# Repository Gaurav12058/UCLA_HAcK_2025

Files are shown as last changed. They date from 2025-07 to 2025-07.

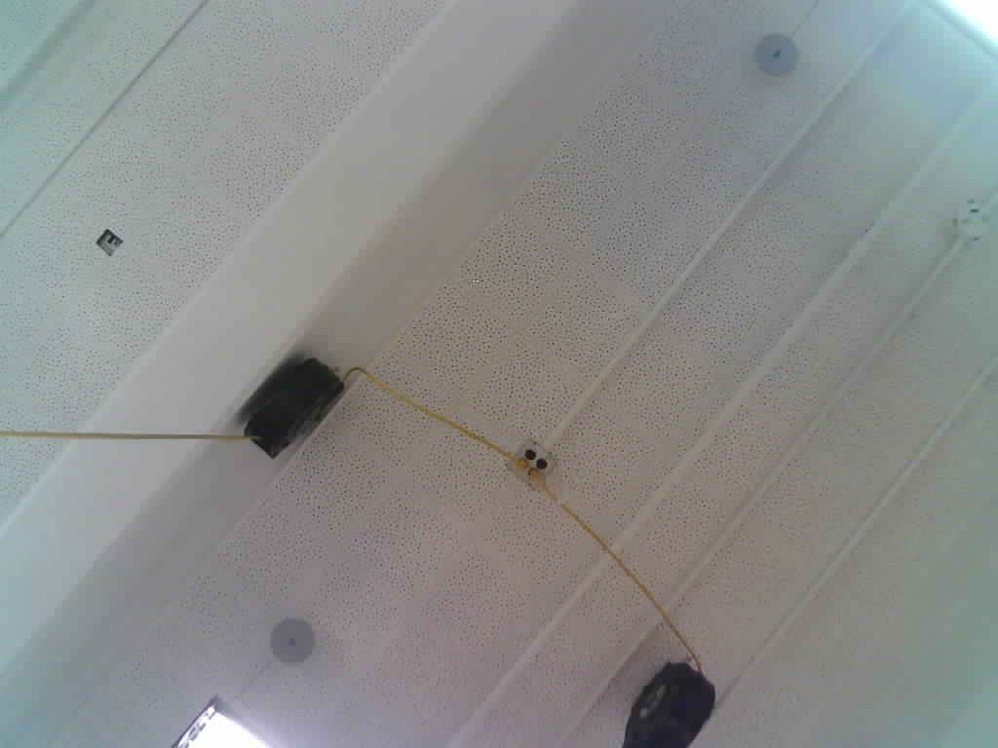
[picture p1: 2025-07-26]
Cam_Setup/downloaded_image.jpg

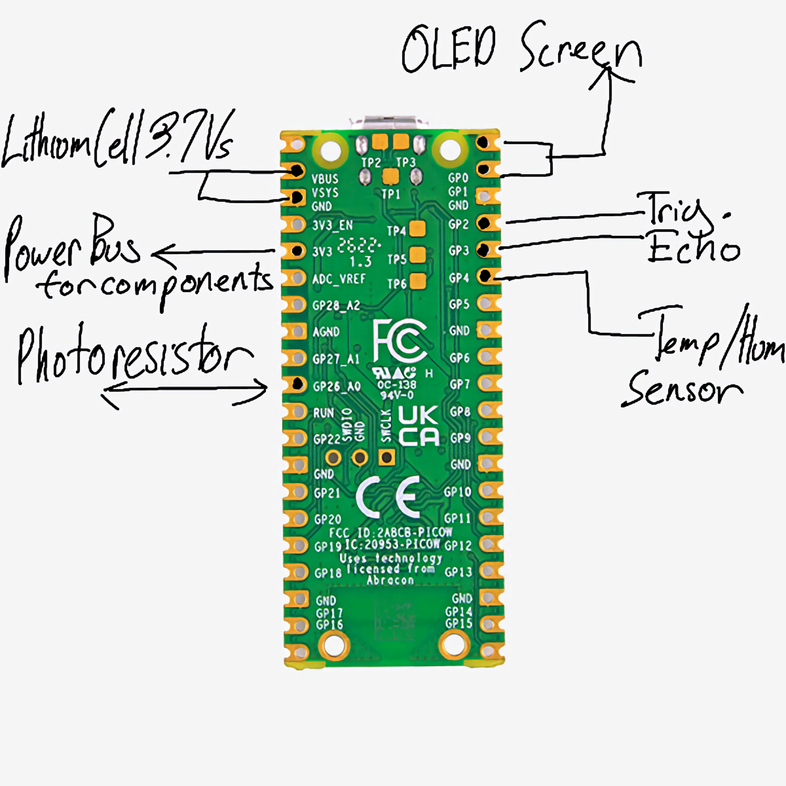
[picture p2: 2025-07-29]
Circuit Schematics/picodiagram.png

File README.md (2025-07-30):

# UCLA HAcK 2025
This REPO contains all the files/code we created during the UCLA HAcK 2025 Challenge

Design Review Presentation: https://drive.google.com/uc?id=1Txfxj7n8K6vMZTReTSZA9UNYm09hm_GZ&export=download

Slides: https://docs.google.com/presentation/d/1NuzraGqRk-Ez6vw4p3RWDepRvH6QMfju0EuOWGAVrpU/edit?usp=sharing

# HAcK 2025 Theme
Wes is a famous jewelry collector.  His most prized possession, a 500 carat diamond, was stolen just last week by a thief that no one could track down…until now. We’ve confirmed the location of the diamond, and we’ll be sending our HAcKers in to retrieve it.  However, we are expecting heavy security, so it won’t be easy finding the jewel. Insider information gave us insight on the security measures they have in place, and you must construct a device that will aid you in deciphering them.

HAcKers will send in one agent equipped with a wearable spy device of their own creation to infiltrate the Secure Base where the diamond is being held. The agent will communicate and send data to their operator (in another room) who will guide the agent by sending messages back to interpret clues, decode information and recover the diamond.

# Technical Challenge
You will need to construct a device (or series of devices) that meets the following requirements:
- Your device(s) must attach to the operator without them having to hold or support them with their hands.
- Your device(s) must resemble wearable accessories/articles of clothing, and should be disguised or otherwise discreet.
- Your device(s) must contain/conceal electrical components
- A device must feature your team logo on it

Our intel suggests that your prototype will need to be able to perform the following tasks:
- Your pico must be able to gather accurate temperature and humidity data to analyze the active field environment
- Your pico must be able to measure light levels and determine distances between objects
- Your ESP-32 cam must be able to take photos that save to the operator’s laptop
- All collected data must be sent to the operator at the bay station for further decoding/analysis

You must also create a website for your operator at the bay station to use:
- Your website must operate the camera, deciding when to  take a picture
- All data received from the agent must be visible on  the website (Temperature in F, Distance in cm, Humidity %, Light in lumens)
- Your website must be able to make api calls to our supercomputer back at HQ (ChatGPT) in order to audibly decipher any additional unknowns
- The results of your api calls must also be viewable on the website
- Your website must be able to communicate information from the operator to the agent in the field

Should anything happen to you or your fellow agents, our team must be able to reproduce your prototypes. As such, you will be required to document the following:
- All code must be uploaded to a GitHub repository and be properly updated.
- You must create and save a CAD for each part of your design.
- You must maintain a simple schematic of your circuits that contains the wiring route and the electrical components used.

# Backend and Frontend setup

- In the backend directory, create a file named '.env', and add the following:

- CONNECT_URL=mqtts://(your URL):(your port)

- MQTT_USER=(your user)

- MQTT_PASS=(your pass)

- Then, while in the backend directory, install the dependencies by running
### `npm install`
- You can start the backend by running 
### `node index.js`

- In a separate terminal, in the frontend directory, install the dependencies by running
### `npm install`
- You can start the frontend by running 
### `npm start`

# Using connections.py for your Pico 2W

- You will be able to use 2 functions in connections.py
    - One for connection to the MQTT broker (connect_mqtt) and one for connecting to WIFI (connect_internet)

    - connect_mqtt(mqtt_server, mqtt_user, mqtt_pass):

        - mqtt_server: the server url which you have obtained by making a free serverless MQTT Broker on HIVEMQ
            - Should look something like: '37##616##db7#bd1##cac997eb01##13.s1.eu.hivemq.cloud'

        - mqtt_user:
            - This is the name of the user you create when you make a credential
                - The purpose of this is just to have a unique user in which the MQTT Broker can understand where the message is coming from 
                - Ex: username = 'pico' when creating credentials for the Raspberry Pi Pico W to send something

        - mqtt_pass:
            - This is the password that goes along with your mqtt_user
            - Just for the broker to validate the user
            - Make this whatever you want, just write it down

        - RETURNS client, which you can use 
            - client.subscribe(b"topic") to subscribe to a topic of your choice
            - client.publish(b"topic", b"message") to publish a message with a topic of your choice
            - client

    - connect_internet( ssid, password ):
        
        - ssid: 
            - This is the name of the wi-fi network you are trying to connect to

        - password:
            - this is the password of the wi-fi network you are trying to connect to

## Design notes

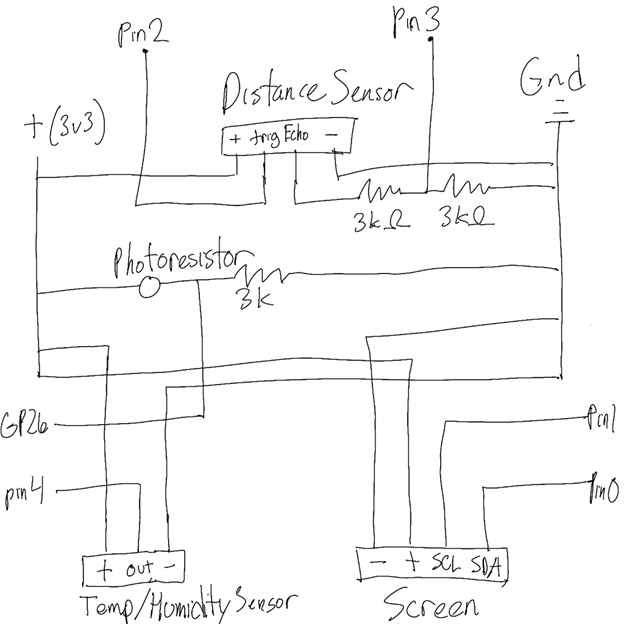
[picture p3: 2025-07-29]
Circuit Schematics/sensordiagram.png

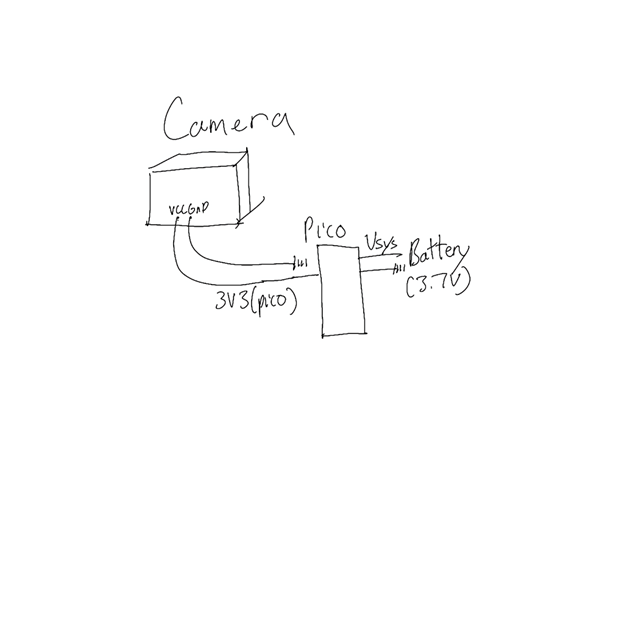
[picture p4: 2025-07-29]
Circuit Schematics/camerapowerdiagram.png

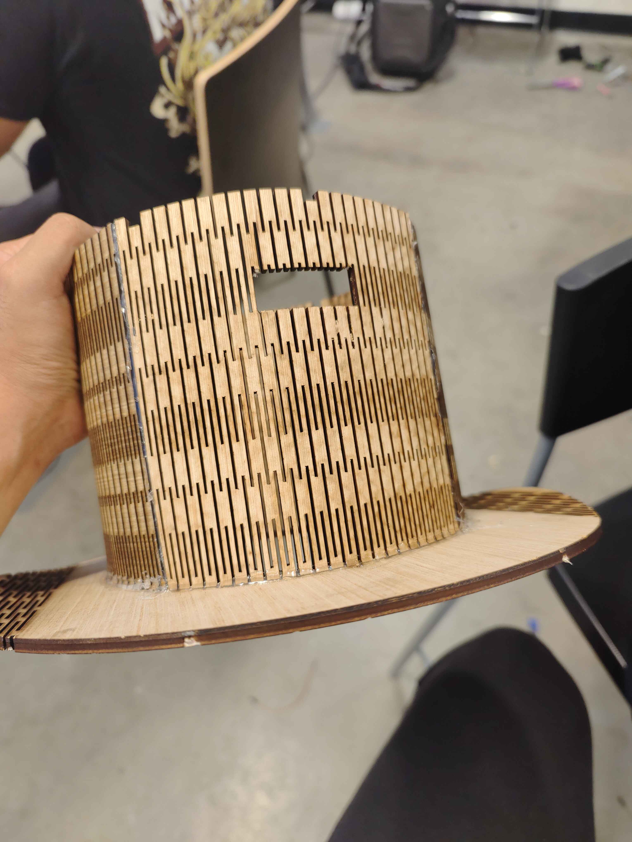
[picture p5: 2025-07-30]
Photos/hat_with_circuit_0.jpg

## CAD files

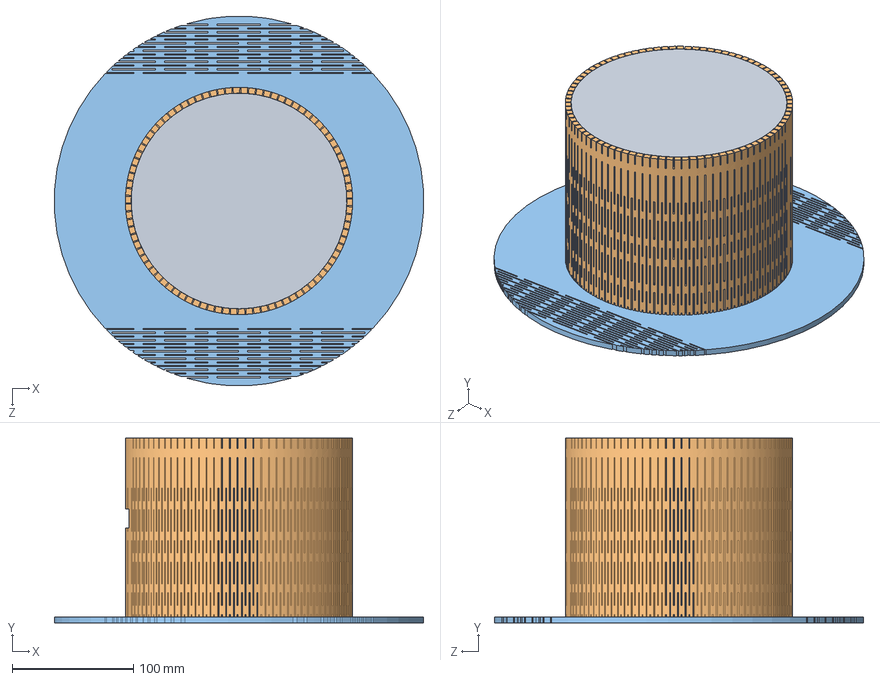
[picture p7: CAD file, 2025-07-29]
CAD/TopHat/HatAssem.SLDASM
304.3 x 152.4 x 304.3 mm
base
Cut-Extrude1
plane x 2

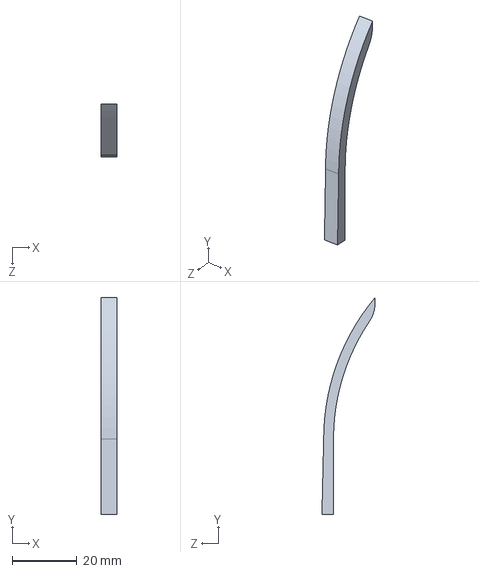
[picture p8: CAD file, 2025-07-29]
CAD/TopHat/Fillet2.SLDPRT
4.78 x 66.8 x 16.4 mm

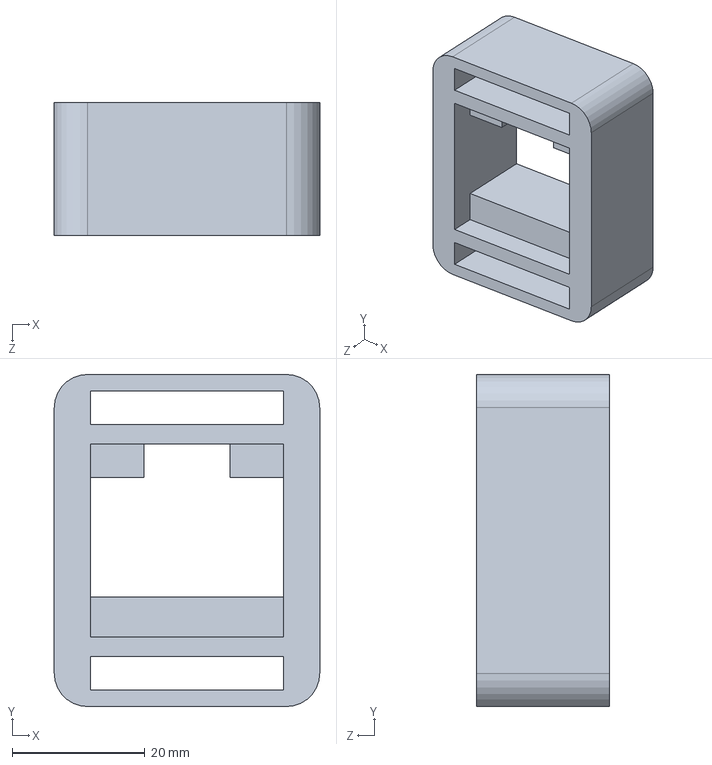
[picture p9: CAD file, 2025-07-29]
CAD/Watch.SLDPRT
40.0 x 50.0 x 20.0 mm

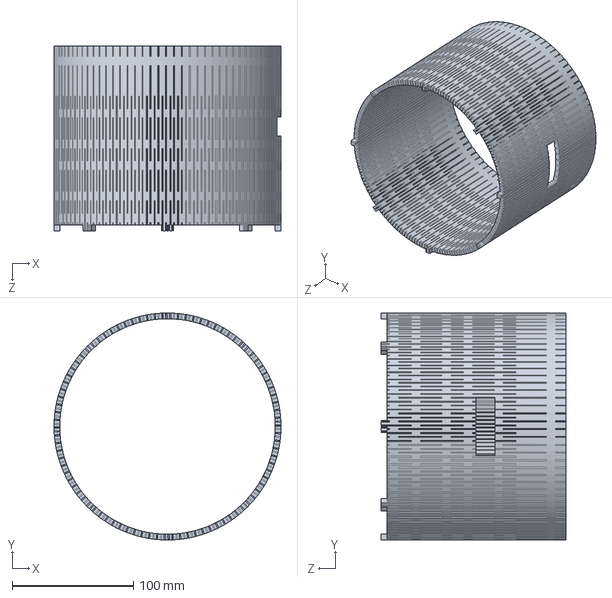
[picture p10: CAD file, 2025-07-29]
CAD/TopHat/Cut-Extrude1.SLDPRT
187.4 x 187.4 x 152.4 mm

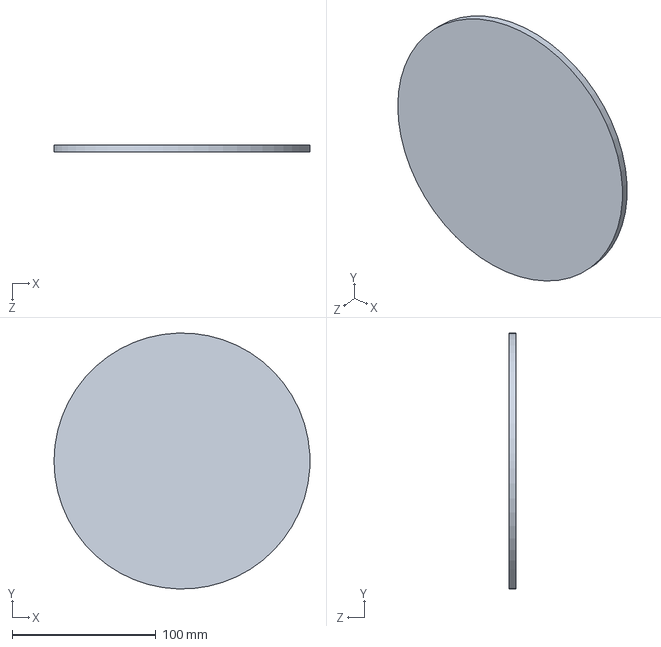
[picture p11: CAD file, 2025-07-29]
CAD/TopHat/plane.SLDPRT
177.8 x 177.7 x 4.78 mm

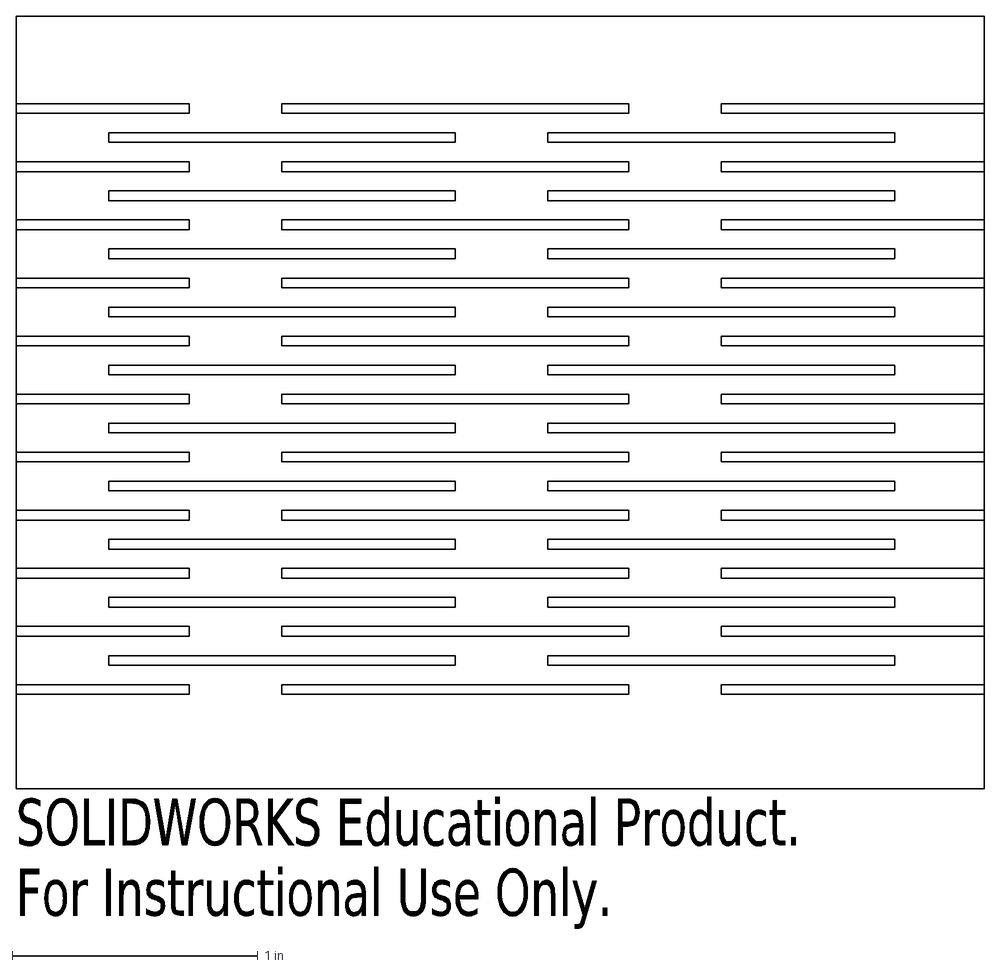
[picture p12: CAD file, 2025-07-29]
CAD/HatLivingHinge.DXF
SOLIDWORKS Educational Product.
For Instructional Use Only.

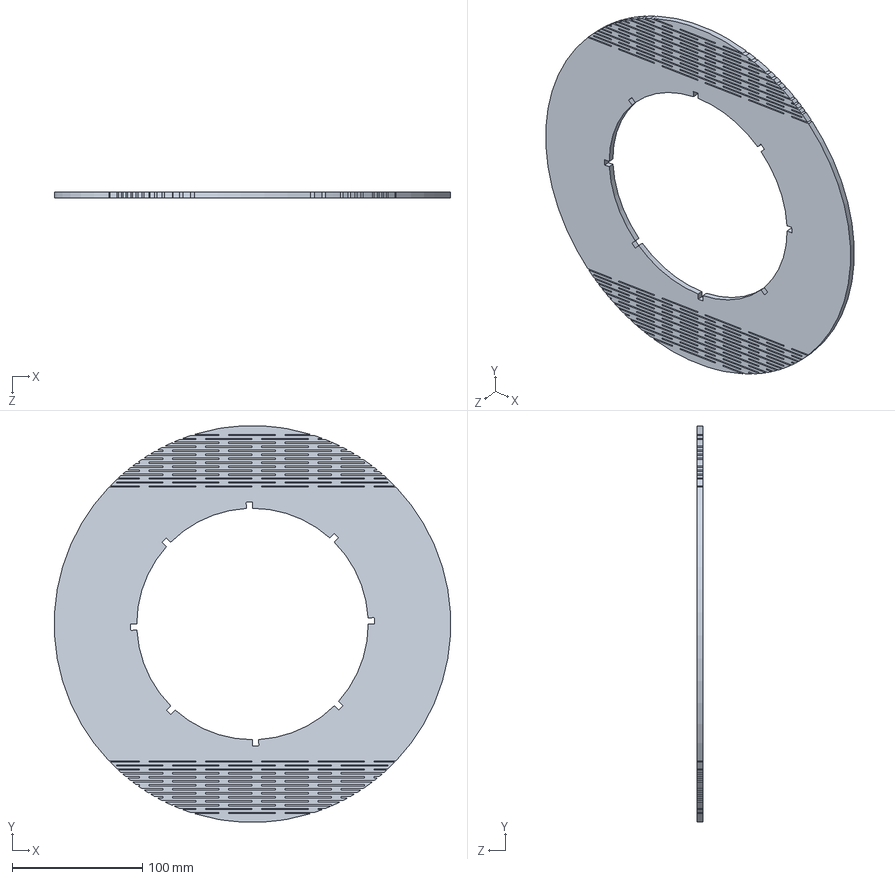
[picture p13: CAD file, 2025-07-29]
CAD/TopHat/base.SLDPRT
304.3 x 304.3 x 4.78 mm

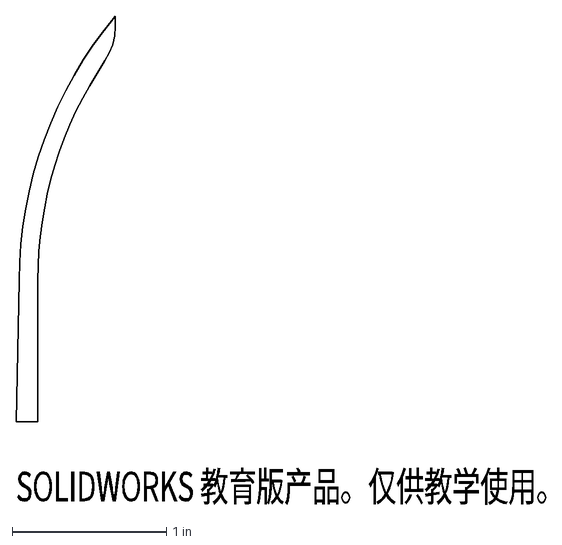
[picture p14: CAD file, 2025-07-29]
CAD/TopHat/Hatframe.DXF
SOLIDWORKS 教育版产品。仅供教学使用。

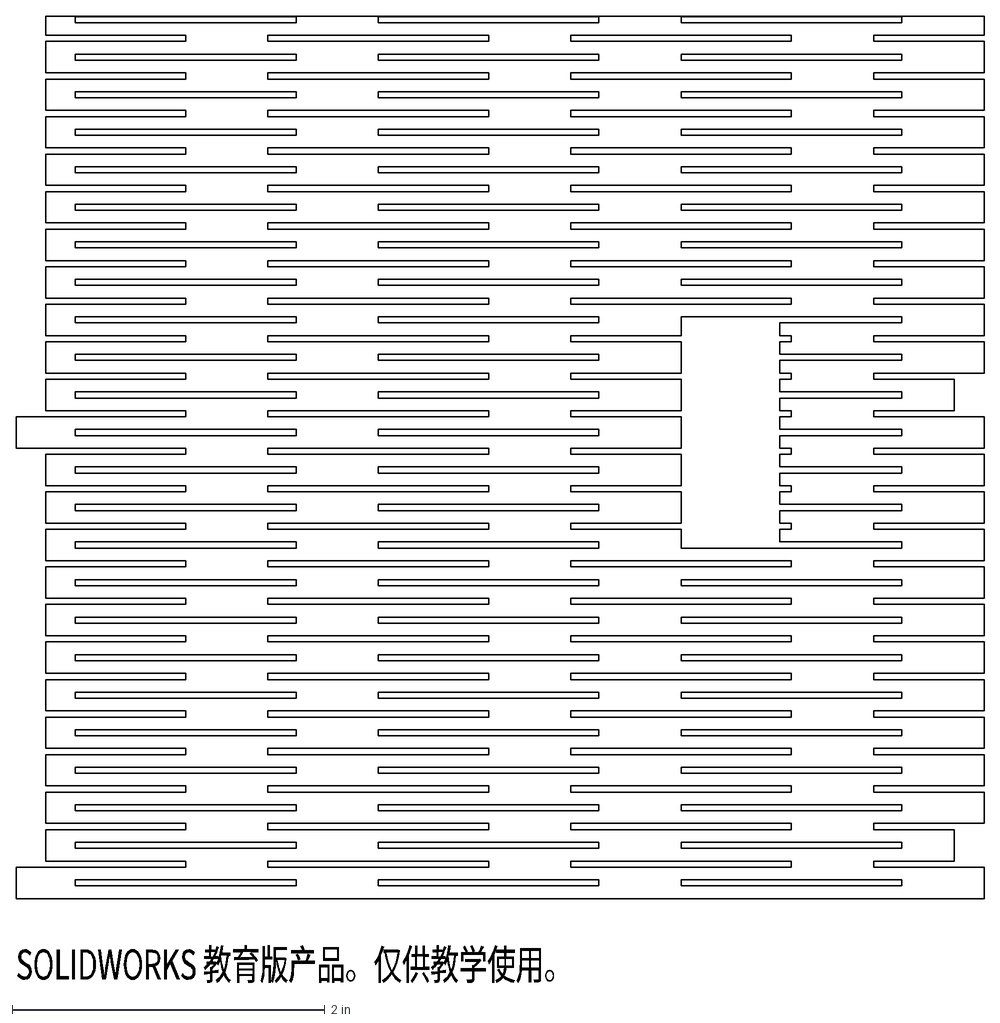
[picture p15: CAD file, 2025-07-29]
CAD/TopHat/Hatboard cut.DXF
SOLIDWORKS 教育版产品。仅供教学使用。

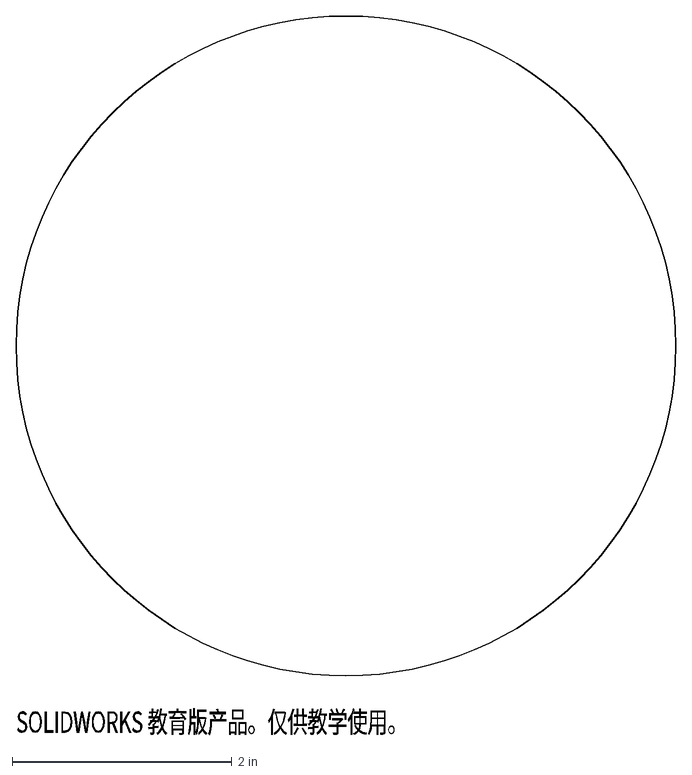
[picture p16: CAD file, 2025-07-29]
CAD/TopHat/HatTopBase.DXF
SOLIDWORKS 教育版产品。仅供教学使用。

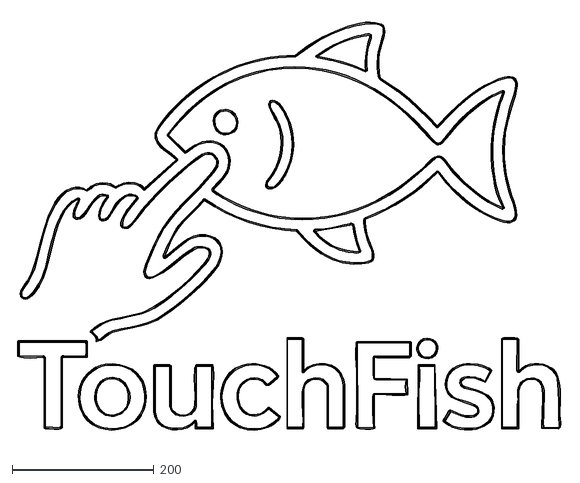
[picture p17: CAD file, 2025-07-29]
CAD/TopHat/TouchFishlogo1.dxf
774.0 x 603.0

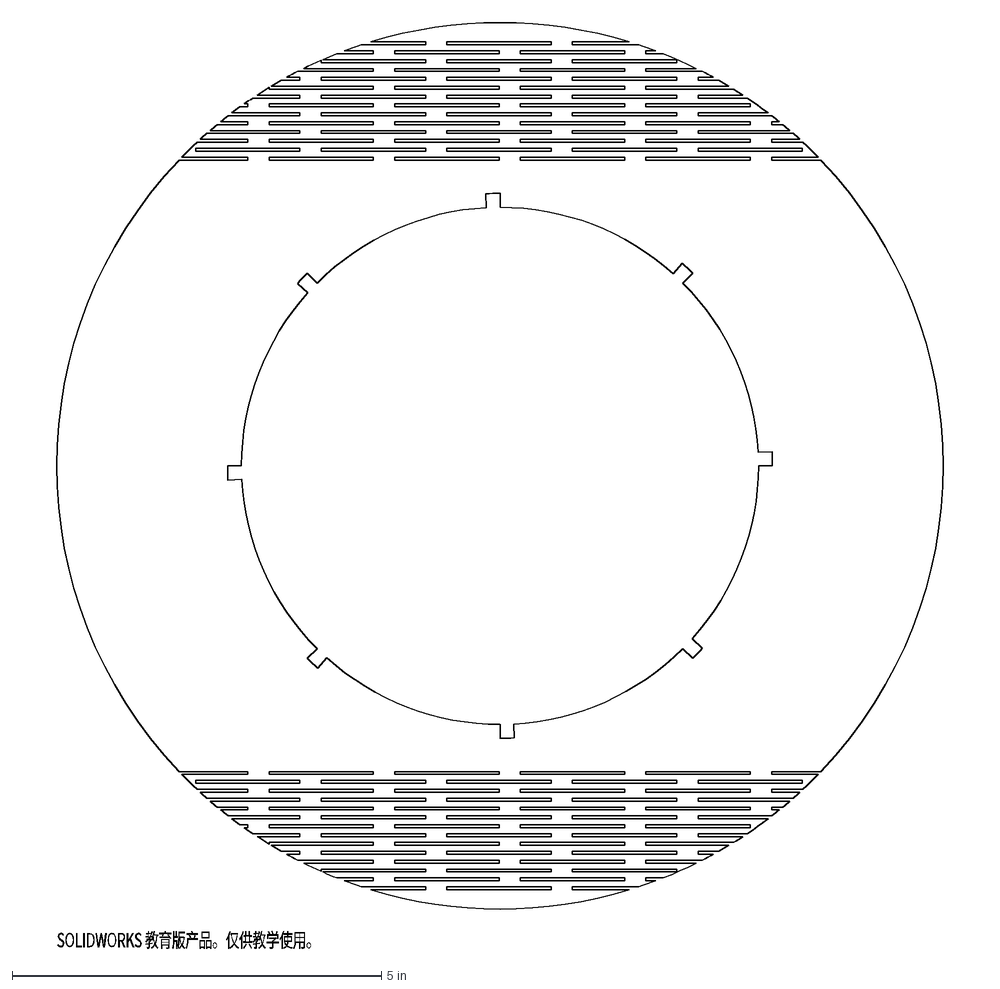
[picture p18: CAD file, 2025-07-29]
CAD/TopHat/HatBase.DXF
SOLIDWORKS 教育版产品。仅供教学使用。

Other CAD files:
CAD/TopHat/Fillet3.SLDPRT
CAD/Watch band.SLDPRT
CAD/Watch Acrylic.SLDPRT
CAD/Team15Watch.STL
CAD/HatTest.SLDPRT
CAD/HatBands.SLDPRT
CAD/HatBands.DXF
CAD/HatTest.DXF
CAD/TopHat/HatCircle.DXF
CAD/Watch Acrylic.DXF
CAD/Watch band.DXF
CAD/Watch.DXF
CAD/Watch.STL

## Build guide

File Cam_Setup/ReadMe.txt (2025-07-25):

ESP32-Camera

Uploading Code to the Camera
-Download Arduino or other C IDE
-Inside of WifiCam change WIFI_SSiD and WIFI_PASS accordingly
-Attach the camera to the daughterboard (says ..-MB on it)
-Connect to computer using USB cable
-Hold the IO0 Button and press the reset button on the Camera to enter programming mode
-Click on 'Tools'->'Manage Libraries', then donwnload the esp32cam library
-Upload the code using the upload button on the IDE
-Click reset and open the serial monitor in Arduino IDE
-Be on a baud rate of 115200 
-Check it connected to wifi successfully 
-Note the IP address -> in the form http:/....

Running the Python Code receive.py
-Make sure the IP Address in receive.py is the same as the one seen in the serial monitor

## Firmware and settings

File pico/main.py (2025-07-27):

from connections import connect_mqtt, connect_internet
from time import sleep
from machine import Pin, I2C, ADC
import time
import dht
from DIYables_MicroPython_OLED import OLED_SSD1306_I2C

# I2C OLED SETUP
i2c = I2C(0, scl=Pin(1), sda=Pin(0), freq=400000)
oled = OLED_SSD1306_I2C(128, 64, i2c)
oled.set_text_size(1)

# Ultrasonic Sensor SETUP
TRIG = Pin(2, Pin.OUT)
ECHO = Pin(3, Pin.IN)

# DHT11 Sensor SETUP
dht_pin = Pin(4, Pin.IN, Pin.PULL_UP)
dht_sensor = dht.DHT11(dht_pin)

# LDR Sensor (Photoresistor) SETUP
ldr = ADC(Pin(26))

# GLOBAL VARIABLE
incoming_oled_text = None  # Stores OLED message from MQTT

# FUNCTIONS
def read_light():
    raw = ldr.read_u16()
    lumenReading = (raw - 95) / 64751 # Our linear equation to convert adc to lumens.
    return lumenReading

def get_distance():
    TRIG.value(0)
    time.sleep_us(2)
    TRIG.value(1)
    time.sleep_us(10)
    TRIG.value(0)

    timeout = 30000
    start = time.ticks_us()
    while ECHO.value() == 0:
        if time.ticks_diff(time.ticks_us(), start) > timeout:
            return None
    pulse_start = time.ticks_us()

    start = time.ticks_us()
    while ECHO.value() == 1:
        if time.ticks_diff(time.ticks_us(), start) > timeout:
            return None
    pulse_end = time.ticks_us()

    duration = time.ticks_diff(pulse_end, pulse_start)
    distance = (duration * 0.0343) / 2
    return round(distance, 1)

def update_oled(distance, temp, hum, light):
    oled.clear_display()
    oled.set_cursor(0, 0)
    oled.println("Distance: {:.2f} cm".format(distance) if distance is not None else "Distance: Error")
    oled.set_cursor(0, 15)
    oled.println("Temp: {:.2f} °F".format(temp) if temp is not None else "Temp: Error")
    oled.set_cursor(0, 30)
    oled.println("Humidity: {:.2f} %".format(hum) if hum is not None else "Humidity: Error")
    oled.set_cursor(0, 45)
    oled.println("Light: {:.4f} lm".format(light) if light is not None else "Light: Error")
    oled.display()

def display_message(msg):
    oled.clear_display()
    oled.set_cursor(0, 0)
    oled.println("Message from Operator:")
    oled.set_cursor(0, 15)
    oled.println(msg[:20])  # 1st line (max 20 chars)
    oled.set_cursor(0, 30)
    oled.println(msg[20:40])  # 2nd line (next 20 chars)
    oled.set_cursor(0, 45)
    oled.println(msg[40:60])  # 3rd line (next 20 chars)
    oled.display()

# CALLBACK FOR MQTT
def on_message(topic, msg):
    global incoming_oled_text
    if topic == b"pico/oled":
        incoming_oled_text = msg.decode()

# MAIN FUNCTION
def main():
    global incoming_oled_text

    print("Connecting to WiFi...")
    connect_internet("HAcK-Project-WiFi-2", password="UCLA.HAcK.2024.Summer")

    client = connect_mqtt(
        "cd2116d580294ecb806ddd465da330cd.s1.eu.hivemq.cloud",
        "Nathan",
        "Ab123456"
    )

    client.set_callback(on_message)
    client.subscribe("pico/oled")

    print("Starting sensors...")
    time.sleep(2)

    while True:
        client.check_msg()  # Check for incoming MQTT messages

        # Display incoming OLED message if any
        if incoming_oled_text:
            print("OLED Message Received:", incoming_oled_text)
            display_message(incoming_oled_text)
            sleep(12)  # Display message for 12 seconds
            incoming_oled_text = None  # Clear after displaying

        try:
            dht_sensor.measure()
            temperature = (dht_sensor.temperature() * 9 / 5) + 32
            humidity = dht_sensor.humidity()
        except Exception as e:
            print("DHT11 Error:", e)
            temperature = None
            humidity = None

        distance = get_distance()
        light_level = read_light()

        update_oled(distance, temperature, humidity, light_level)

        # Publish sensor data to MQTT topics
        client.publish("pico/temperature", str(temperature))
        client.publish("pico/humidity", str(humidity))
        client.publish("pico/distance", str(distance))
        client.publish("pico/lightlevel", str(light_level))

        sleep(2)

# RUN FILE
if __name__ == "__main__":
    try:
        main()
    except KeyboardInterrupt:
        print("Stopped by user")

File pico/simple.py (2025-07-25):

import usocket as socket
import ustruct as struct

from ubinascii import hexlify


class MQTTException(Exception):
    pass


class MQTTClient:
    def __init__(
        self,
        client_id,
        server,
        port=0,
        user=None,
        password=None,
        keepalive=0,
        ssl=None,
    ):
        if port == 0:
            port = 8883 if ssl else 1883
        self.client_id = b"pico"  # You can customize this if needed
        self.sock = None
        self.server = "cd2116d580294ecb806ddd465da330cd.s1.eu.hivemq.cloud"
        self.port = 8883
        self.ssl = True
        self.pid = 0
        self.cb = None
        self.user = "Nathan"
        self.pswd = "Ab123456"
        self.keepalive = keepalive
        self.lw_topic = None
        self.lw_msg = None
        self.lw_qos = 0
        self.lw_retain = False

    def _send_str(self, s):
        self.sock.write(struct.pack("!H", len(s)))
        self.sock.write(s)

    def _recv_len(self):
        n = 0
        sh = 0
        while 1:
            b = self.sock.read(1)[0]
            n |= (b & 0x7F) << sh
            if not b & 0x80:
                return n
            sh += 7

    def set_callback(self, f):
        self.cb = f

    def set_last_will(self, topic, msg, retain=False, qos=0):
        assert 0 <= qos <= 2
        assert topic
        self.lw_topic = topic
        self.lw_msg = msg
        self.lw_qos = qos
        self.lw_retain = retain

    def connect(self, clean_session=True):
        self.sock = socket.socket()
        addr = socket.getaddrinfo(self.server, self.port)[0][-1]
        self.sock.connect(addr)
        if self.ssl:
            self.sock = self.ssl.wrap_socket(self.sock, server_hostname=self.server)
        premsg = bytearray(b"\x10\0\0\0\0\0")
        msg = bytearray(b"\x04MQTT\x04\x02\0\0")

        sz = 10 + 2 + len(self.client_id)
        msg[6] = clean_session << 1
        if self.user:
            sz += 2 + len(self.user) + 2 + len(self.pswd)
            msg[6] |= 0xC0
        if self.keepalive:
            assert self.keepalive < 65536
            msg[7] |= self.keepalive >> 8
            msg[8] |= self.keepalive & 0x00FF
        if self.lw_topic:
            sz += 2 + len(self.lw_topic) + 2 + len(self.lw_msg)
            msg[6] |= 0x4 | (self.lw_qos & 0x1) << 3 | (self.lw_qos & 0x2) << 3
            msg[6] |= self.lw_retain << 5

        i = 1
        while sz > 0x7F:
            premsg[i] = (sz & 0x7F) | 0x80
            sz >>= 7
            i += 1
        premsg[i] = sz

        self.sock.write(premsg, i + 2)
        self.sock.write(msg)
        # print(hex(len(msg)), hexlify(msg, ":"))
        self._send_str(self.client_id)
        if self.lw_topic:
            self._send_str(self.lw_topic)
            self._send_str(self.lw_msg)
        if self.user:
            self._send_str(self.user)
            self._send_str(self.pswd)
        resp = self.sock.read(4)
        assert resp[0] == 0x20 and resp[1] == 0x02
        if resp[3] != 0:
            raise MQTTException(resp[3])
        return resp[2] & 1

    def disconnect(self):
        self.sock.write(b"\xe0\0")
        self.sock.close()

    def ping(self):
        self.sock.write(b"\xc0\0")

    def publish(self, topic, msg, retain=False, qos=0):
        pkt = bytearray(b"\x30\0\0\0")
        pkt[0] |= qos << 1 | retain
        sz = 2 + len(topic) + len(msg)
        if qos > 0:
            sz += 2
        assert sz < 2097152
        i = 1
        while sz > 0x7F:
            pkt[i] = (sz & 0x7F) | 0x80
            sz >>= 7
            i += 1
        pkt[i] = sz
        # print(hex(len(pkt)), hexlify(pkt, ":"))
        self.sock.write(pkt, i + 1)
        self._send_str(topic)
        if qos > 0:
            self.pid += 1
            pid = self.pid
            struct.pack_into("!H", pkt, 0, pid)
            self.sock.write(pkt, 2)
        self.sock.write(msg)
        if qos == 1:
            while 1:
                op = self.wait_msg()
                if op == 0x40:
                    sz = self.sock.read(1)
                    assert sz == b"\x02"
                    rcv_pid = self.sock.read(2)
                    rcv_pid = rcv_pid[0] << 8 | rcv_pid[1]
                    if pid == rcv_pid:
                        return
        elif qos == 2:
            assert 0

    def subscribe(self, topic, qos=0):
        assert self.cb is not None, "Subscribe callback is not set"
        pkt = bytearray(b"\x82\0\0\0")
        self.pid += 1
        struct.pack_into("!BH", pkt, 1, 2 + 2 + len(topic) + 1, self.pid)
        # print(hex(len(pkt)), hexlify(pkt, ":"))
        self.sock.write(pkt)
        self._send_str(topic)
        self.sock.write(qos.to_bytes(1, "little"))
        while 1:
            op = self.wait_msg()
            if op == 0x90:
                resp = self.sock.read(4)
                # print(resp)
                assert resp[1] == pkt[2] and resp[2] == pkt[3]
                if resp[3] == 0x80:
                    raise MQTTException(resp[3])
                return

    # Wait for a single incoming MQTT message and process it.
    # Subscribed messages are delivered to a callback previously
    # set by .set_callback() method. Other (internal) MQTT
    # messages processed internally.
    def wait_msg(self):
        res = self.sock.read(1)
        self.sock.setblocking(True)
        if res is None:
            return None
        if res == b"":
            raise OSError(-1)
        if res == b"\xd0":  # PINGRESP
            sz = self.sock.read(1)[0]
            assert sz == 0
            return None
        op = res[0]
        if op & 0xF0 != 0x30:
            return op
        sz = self._recv_len()
        topic_len = self.sock.read(2)
        topic_len = (topic_len[0] << 8) | topic_len[1]
        topic = self.sock.read(topic_len)
        sz -= topic_len + 2
        if op & 6:
            pid = self.sock.read(2)
            pid = pid[0] << 8 | pid[1]
            sz -= 2
        msg = self.sock.read(sz)
        self.cb(topic, msg)
        if op & 6 == 2:
            pkt = bytearray(b"\x40\x02\0\0")
            struct.pack_into("!H", pkt, 2, pid)
            self.sock.write(pkt)
        elif op & 6 == 4:
            assert 0
        return op

    # Checks whether a pending message from server is available.
    # If not, returns immediately with None. Otherwise, does
    # the same processing as wait_msg.
    def check_msg(self):
        self.sock.setblocking(False)
        return self.wait_msg()

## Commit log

2025-07-25 Added functionality for pi pico 2 and added basic framework for the app.js and app.css. Have not tested on whether the server updating works yet.
2025-07-26 Added camera functionality
2025-07-26 added camera live stream to website
2025-07-27 transferred all REST API calls to Socket
2025-07-27 photo resistor now measures adc value on website
2025-07-27 photo resistor now measures lumens instead of adc
2025-07-27 fixed lumen not displaying properly on screen
    [main.py]
2025-07-29 created CAD and circuit folder
2025-07-29 added CAD files
    [HatBands.DXF, HatBands.SLDPRT, HatLivingHinge.DXF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]
2025-07-29 add CAD file
    [HatBase.DXF, HatCircle.DXF, HatTopBase.DXF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]
2025-07-29 added circuit diagrams
2025-07-29 Add hat assembly
    [Cut-Extrude1.SLDPRT, Fillet2.SLDPRT, Fillet3.SLDPRT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]
2025-07-30 removed duplicate esp32 code
